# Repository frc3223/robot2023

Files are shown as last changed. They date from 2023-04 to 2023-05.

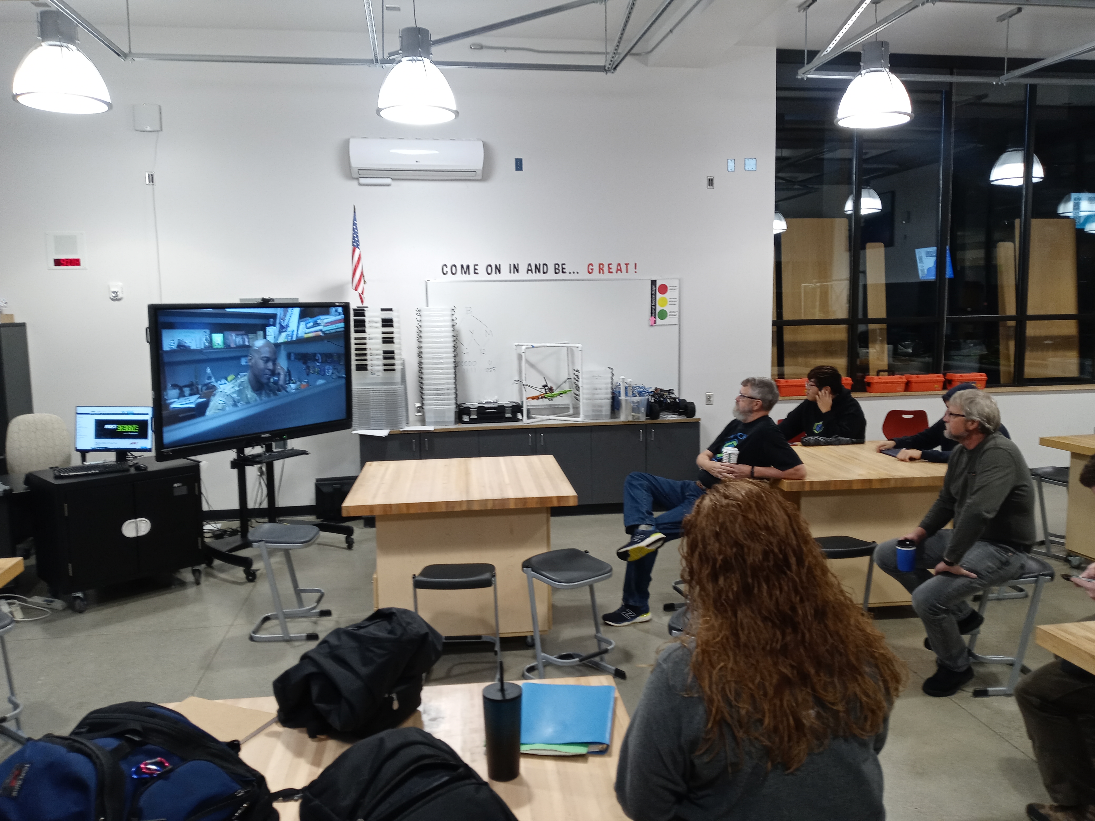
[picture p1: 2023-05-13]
Photos and Videos for RoCK/20230107_090814.jpg

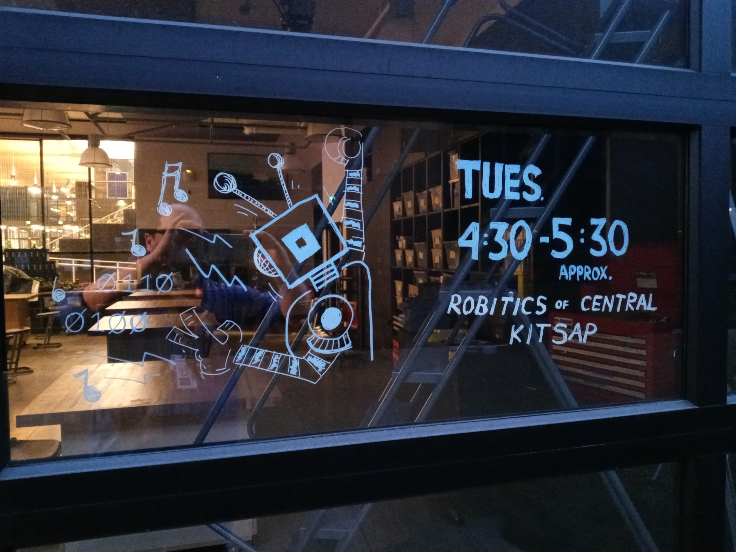
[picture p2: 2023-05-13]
Photos and Videos for RoCK/20221025_181121.jpg

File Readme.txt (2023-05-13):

We use two Audrinos.

one for the Linefollower and Winch (ROCKRadioLineFollowerEncoder)
and the other for the robotic arm. (ROCK_DOD_Challenge)

ROBOTIC ARM:
For the arm you have to use the "LAFVIN_Robot_arm_9_4_15.apk" as an app on an Android Phone. (apple is not compatible.)
you then use the "Lesson_8_Bluetooth_Controlling_Arm" code. For further opertational instruction seek LAFVIN's Lesson 8 tutorial.

Looking at the top of the robot (winch side towards you) the servos go into these spots on the audrino

left bottom servo = 5
right bottom servo = 3
servo connecting to the claw = 6**
servo that controls the claw = 9

**(Up and down controls are reversed.)

LINE FOLLOWER:
To use the Linefollower the code is "ROCKRadioLineFollowEncoder.ino"
Then, to turn on the robot's line follower, flip the left long switch all the way up on the Controller. Then flip the left small switch after alining the sensors on the robot (which is on the bottom front end of the robot) to the black line. It should follow the line.

(The Line Following Code is also a part of the Winch Code.)

WINCH:
Flip the left long switch to the middle and then flip the left small switch to activate the winch. use the left Joystick to controll the up and down motion of the winch. Left makes it go Up and Right makes it go Down.

There are indicators on the robot that changes color based on what mode you are in.

Green = Radio (the robot is in drive mode)

Orange + Winch (the robot is in Winch mode)

Red = Line Follower (the robot is in line following mode)

FINAL BUILD - CAD:
 - ARM:
	- Primary:
		- Base Piece
		- Claw Attachment
		- Claw Part
		- End Piece
		- Main Section
	- Spacers:
		- Axle Spacer
		- Base Spacer
		- Claw Mount Spacer
 - MISC.:
	- MindsEye Bracket
	- Servo Mount Bracket
There are five PRIMARY components to the arm (and their affiliated spacers). The "Base Piece" connects via four pins to the main base of the robot, which supports the rest of the arm. The "End Piece" is the first
free-rotating section of the arm (features the RoCK logo), supported by two servos. The "Main Section" features 15 hexagonal holes, allowing for a convenient way to fasten zip-ties to secure rogue wires. The "Main Section"
also attaches itself to the "End Piece", increasing the length of the arm. The "Claw Attachment" is the next free-rotating section of the arm, supported by one servo on the "Main Section". With this component, two "Claw Part" 
units move symmetrically with one servo on the "Claw Attachment".

OBSERVATIONS:
The "MindsEye Bracket" was our solution to a dilema in assembling the base of the robot. Since the manufactured steering brackets—enabling a fixed range of translational movement for the robot—were stripped due to overuse, we 
3D-printed our own.

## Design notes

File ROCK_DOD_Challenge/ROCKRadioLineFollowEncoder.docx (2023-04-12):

// ROCKRadioLineFollowEncoder 3-19-2023

#include <Servo.h>

#include <MINDSi.h>

#include "Encoder.h"

/***************************************************

/ Radio auxilliary Ch 5 & 6 are mapped to switches A & B.

/ Reads radio Ch 5 & 6 pulse widths on pins 7 & 8 and

/ chooses functions depending on radio switchs A & B positions.

/ Encoder is on digital pins 0 (A blue) and 1 (B yellow)

/ If the order is reversed, going backwards would read as positive rpm and vice versa

/ Wheel diameter is about 4.45 in.; circumference is pi*dia

/ Moving 10 feet requires (120/wheel circumference) revolutions

/ 3:1 gear ratio

/ drive motor is on pin 4 and steering is on pin 5

/ winch is on pin 6, and is controlled by radio channel 4,

/ left joystich (L/R) on arduino pin 9.

/***************************************************/

Servo steer, drive, winch;

unsigned long duration7; //pulse width on pin 7

unsigned long duration8; //pulse width on pin 8

const int inchesTravel = 120;

const float wheelDia = 4.45;

float shaftRevs = inchesTravel/(3.14 * wheelDia) * 3;

float rev;

float revStop;

const int encoderPins[2] = {0, 1}; // an array

const int threshold = 2000; // QTI threshold

bool funcB = false;

void setup() {

// Serial.begin(9600);

pinMode(11, OUTPUT); // green LED indicating radio drive

pinMode(12, OUTPUT); // red LED indicating autonomous mode

digitalWrite(11, LOW);

digitalWrite(12, LOW);

pinMode(7, INPUT); // radio channel 5

pinMode(8, INPUT); // radio channel 6

encoder::begin(encoderPins[0], encoderPins[1]);

drive.attach(4);

steer.attach(5);

drive.write(90);

steer.write(90);

winch.attach(6);

winch.write(55); // 55 sets winch "off"

// if needed, winch can be disabled by attaching it to an unused pin

delay(2000); //wait for 2 seconds to arm the ESC

}

void loop() {

duration7 = pulseIn(7, HIGH);

duration8 = pulseIn(8, HIGH);

if ((duration7 < 1250) && (duration8 < 1250)) {functionA();}

if ((duration7 > 1750) && (duration8 < 1250)) {functionB();}

if ((duration7 < 1250) && (duration8 > 1250) && (duration8 < 1750 )) {functionC();}

if ((duration7 > 1750) && (duration8 > 1250) && (duration8 < 1750 )) {functionD();}

if ((duration7 < 1250) && (duration8 > 1750)) {functionE();}

if ((duration7 > 1750) && (duration8 > 1750)) {functionF();}

// Serial.print(duration7);

// Serial.print("\t");

// Serial.println(duration8);

}

void functionA() {

// radio drive

digitalWrite(12, LOW);

digitalWrite(11, HIGH);

drive.write(getRadio(2));

steer.write(getRadio(3));

winch.write(getRadio(9));

funcB = false;

}

void functionB() {

// line follower

digitalWrite(11, LOW);

digitalWrite(12, HIGH);

rev = encoder::getRev();

revStop = rev + shaftRevs;

//run along line until rev exceeds revStop

while ((rev < revStop) && !funcB) {

drive.write(100);

// follow black line

if (QTI(A0) > threshold) {

steer.write(65);

} else if (QTI(A2) > threshold) {

steer.write(115);

} else if (QTI(A1) > threshold) {

steer.write(90);

}

rev = encoder::getRev();

duration7 = pulseIn(7, HIGH); // check if radio control changed

duration8 = pulseIn(8, HIGH);

if ((duration7 < 1250) && (duration8 < 1250)) {funcB = true;}

}

// stop motor

drive.write(90);

delay(100);

funcB = true;

}

void functionC() {Serial.println("function C");}

void functionD() {Serial.println("function D");}

void functionE() {Serial.println("function E");}

void functionF() {Serial.println("function F");}

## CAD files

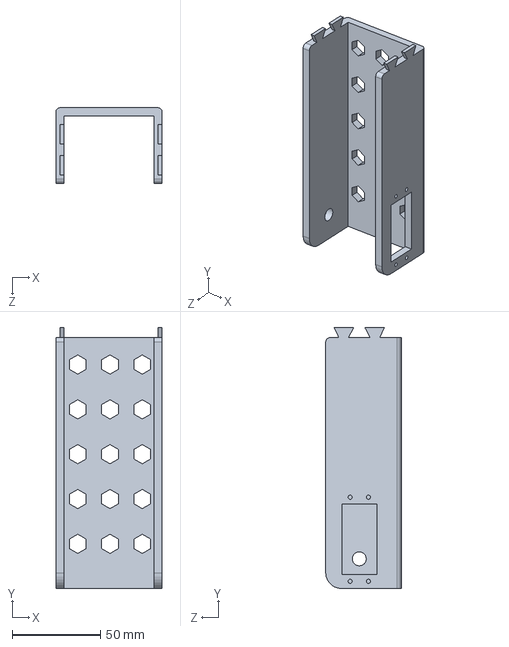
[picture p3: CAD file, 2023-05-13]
Final Build - CAD/Arm Build/Main Arm Section - Claw Attachment - Updated - Version 2.SLDPRT
60.3 x 147.9 x 42.9 mm

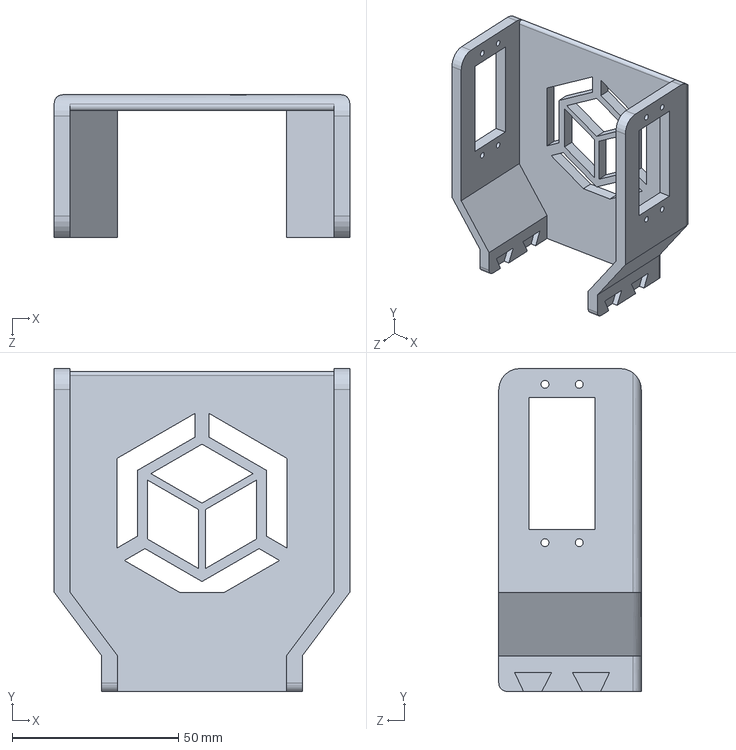
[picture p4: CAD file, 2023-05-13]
Final Build - CAD/Arm Build/Main Arm Section - End Piece - 2 Servos - Version 2.SLDPRT
88.9 x 97.2 x 42.9 mm

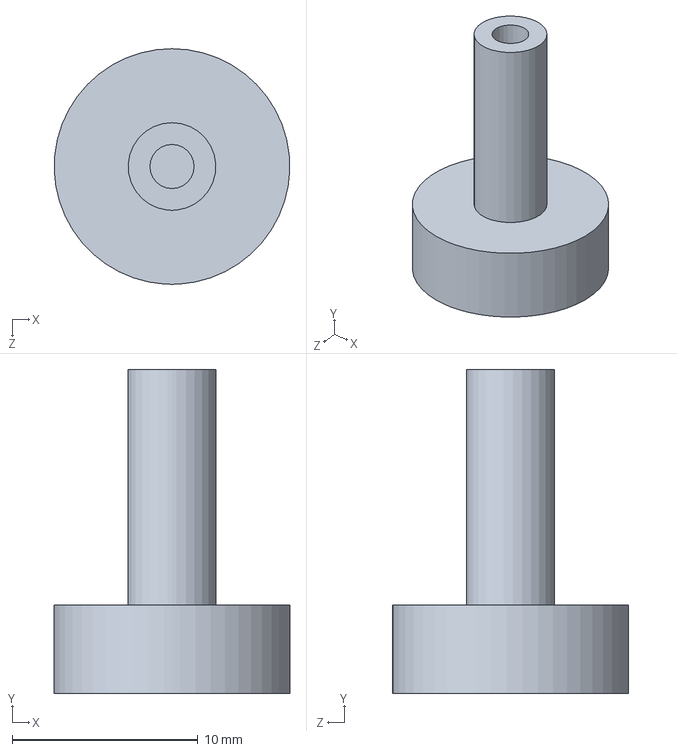
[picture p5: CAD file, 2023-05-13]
Final Build - CAD/Arm Build/Claw Mount Spacer.SLDPRT
12.7 x 17.5 x 12.7 mm

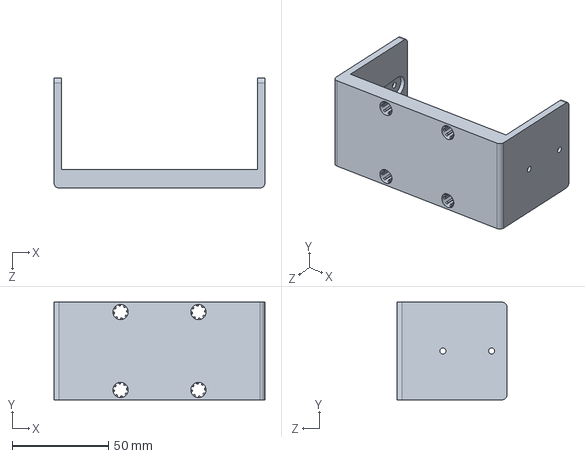
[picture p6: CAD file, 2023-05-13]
Final Build - CAD/Arm Build/Arm Base Piece - Updated - Version 4.SLDPRT
109.7 x 50.8 x 57.2 mm

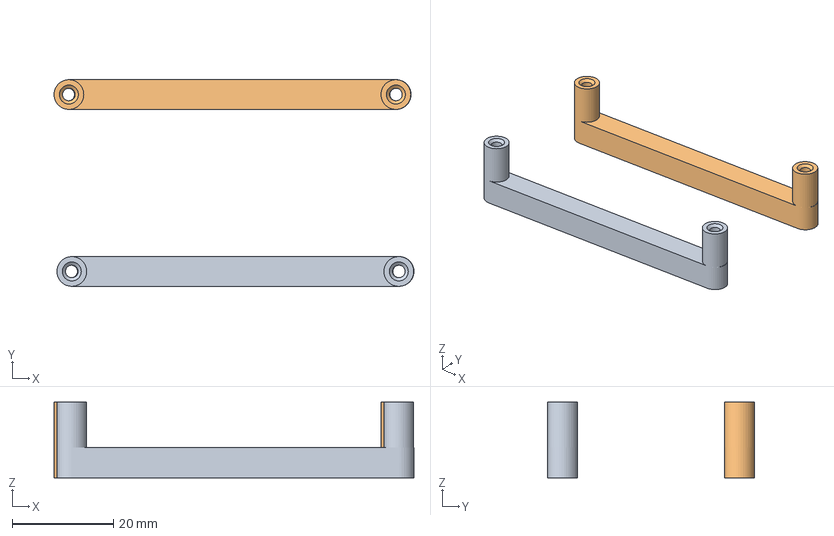
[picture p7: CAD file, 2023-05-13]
Final Build - CAD/Arm Build/AI3MSPRO_MindsEye Bracket.3mf
71.3 x 40.9 x 15.0 mm
MindsEye Bracket.STL
MindsEye Bracket.STL(1)

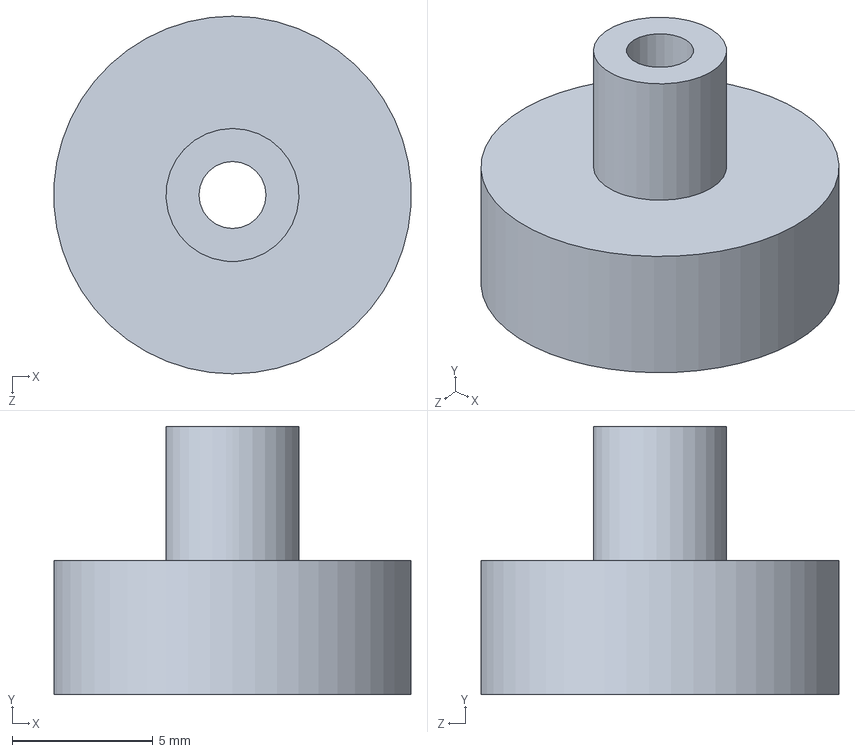
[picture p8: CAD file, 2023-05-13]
Final Build - CAD/Arm Build/Axle Spacer.SLDPRT
12.7 x 9.53 x 12.7 mm

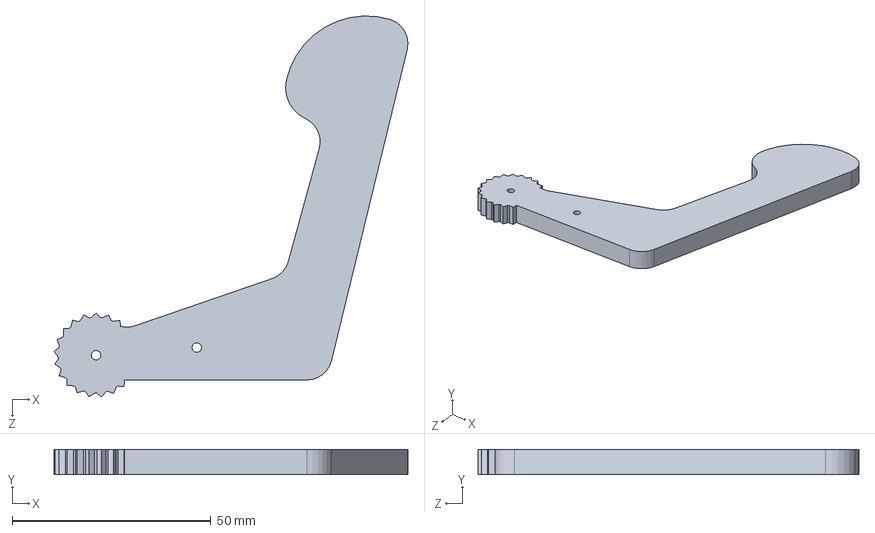
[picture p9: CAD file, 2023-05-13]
Final Build - CAD/Arm Build/Claw Part for Arm - Updated.SLDPRT
88.9 x 6.35 x 95.7 mm

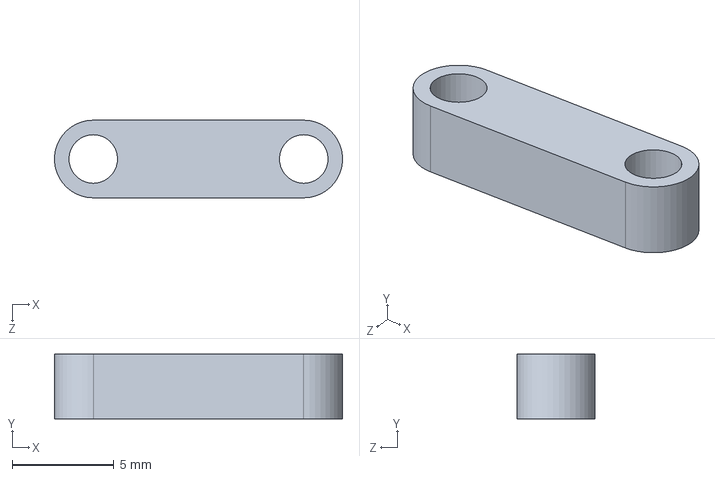
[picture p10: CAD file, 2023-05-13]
Final Build - CAD/Arm Build/Servo Mount Bracket.SLDPRT
14.1 x 3.17 x 3.81 mm

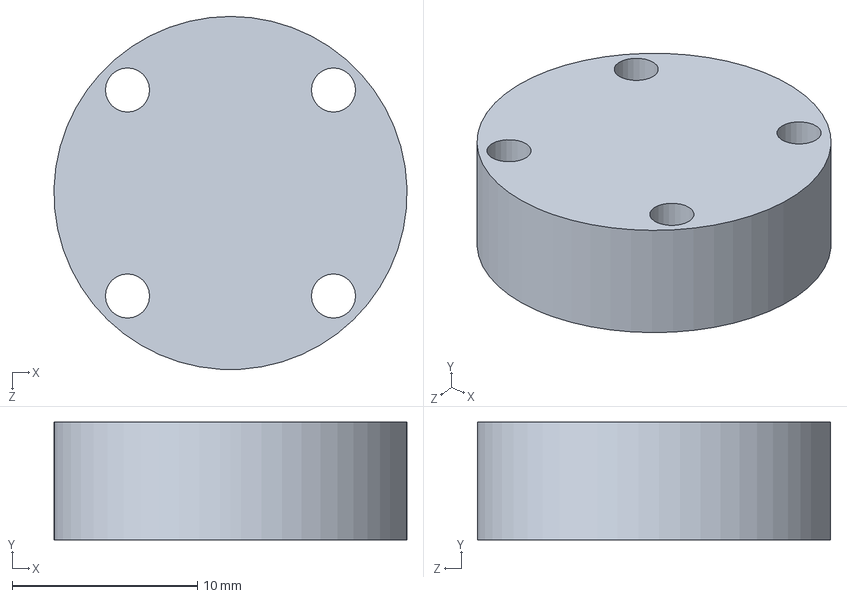
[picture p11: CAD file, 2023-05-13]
Final Build - CAD/Arm Build/Base Spacer.SLDPRT
19.0 x 6.35 x 19.1 mm

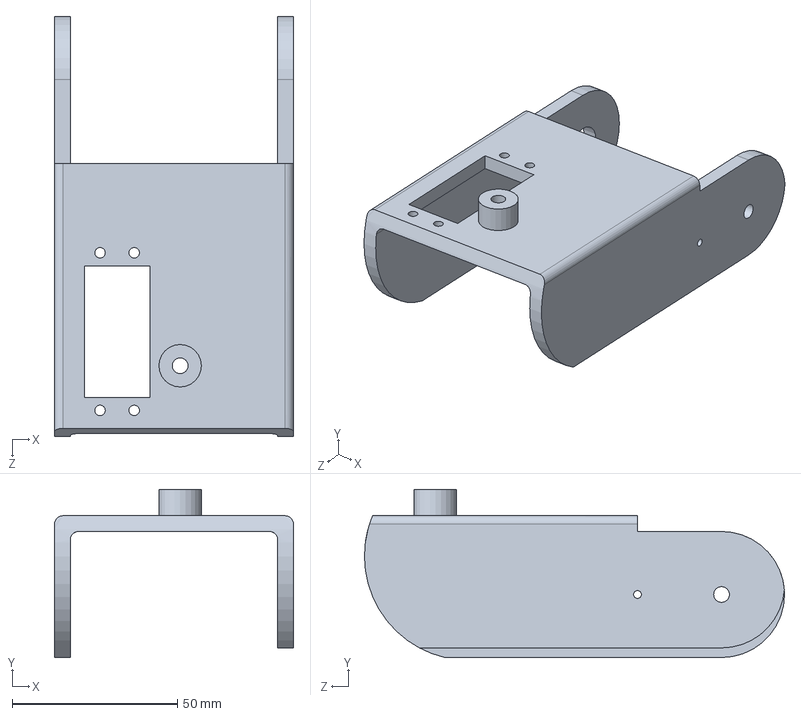
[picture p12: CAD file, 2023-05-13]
Final Build - CAD/Arm Build/Arm - Claw Attachment - Updated - Version 4.SLDPRT
72.2 x 50.8 x 127.0 mm

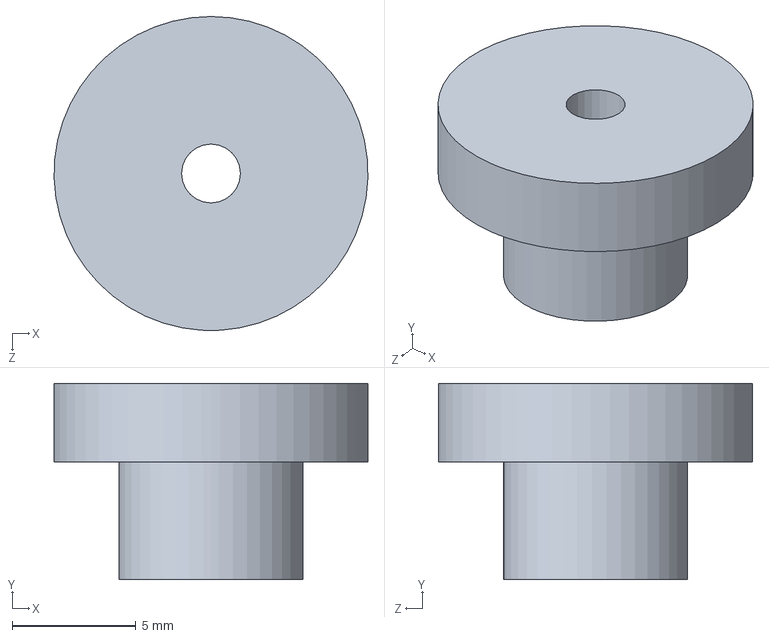
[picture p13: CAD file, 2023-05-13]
Final Build - CAD/Arm Build/Axle Spacer - Other Half.SLDPRT
12.7 x 7.94 x 12.7 mm

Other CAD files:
Final Build - CAD/Arm Build/Arm - Claw Attachment - Updated - Version 4.STL
Final Build - CAD/Arm Build/Arm Base Piece - Updated - Version 4.STL
Final Build - CAD/Arm Build/Axle Spacer - Other Half.STL
Final Build - CAD/Arm Build/Axle Spacer.STL
Final Build - CAD/Arm Build/Base Spacer.STL
Final Build - CAD/Arm Build/Claw Mount Spacer.STL
Final Build - CAD/Arm Build/Claw Part for Arm - Updated.STL
Final Build - CAD/Arm Build/Main Arm Section - Claw Attachment - Updated - Version 2.STL
Final Build - CAD/Arm Build/Main Arm Section - End Piece - 2 Servos - Version 2.STL
Final Build - CAD/Arm Build/Servo Mount Bracket.STL

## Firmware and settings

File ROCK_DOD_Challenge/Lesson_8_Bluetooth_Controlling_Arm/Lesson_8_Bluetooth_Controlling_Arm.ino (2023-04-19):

#include <Servo.h>  // add the servo libraries
//  Lesson_8_Bluetooth_Controlling_Arm mod
//  Modified so two servos control lower arm; no sideways movement
//  Slowed down servo rates by changing summation from 8 to 4
//  Moved servo limits to follow summations
Servo myservo1;  // create servo object to control a servo
Servo myservo2;
Servo myservo3;
Servo myservo4;
int pos1=90, pos2=90, pos3=90, pos4=90;  // define the variable of 4 servo angle and assign the initial value( that is the boot posture angle value)
char val;
int incomingByte = 0;          // Received data byte
String inputString = "";         // Used to store received content
boolean newLineReceived = false; // Previous data end flag
boolean startBit  = false;  //Acceptance Agreement Start Sign
int num_reveice=0;
void setup()
{
   // boot posture
  myservo1.write(pos1);  
//  delay(1000);
  myservo2.write(pos2);
  myservo3.write(pos3);
  myservo4.write(pos4);
  delay(1500);

  Serial.begin(9600); //  set the baud rate to 9600
}

void loop() 
{
  myservo1.attach(3);  // set the control pin of servo 1 to D3
  myservo2.attach(5);  // set the control pin of servo 2 to D5
  myservo3.attach(6);   // set the control pin of servo 3 to D6
  myservo4.attach(9);   // set the control pin of servo 4 to D9

while (Serial.available())
  {
    incomingByte = Serial.read();              //One byte by byte, the next sentence is read into a string array to form a completed packet
    if (incomingByte == '%')
    {
      num_reveice = 0;
      startBit = true;
    }
    if (startBit == true)
    {
      num_reveice++;
      inputString += (char) incomingByte;     
    }
    if (startBit == true && incomingByte == '#')
    {
      newLineReceived = true;
      startBit = false;
    }
    
    if(num_reveice >= 20)
    {
      num_reveice = 0;
      startBit = false;
      newLineReceived = false;
      inputString = "";
    }  
  }



if(newLineReceived)
{
 // Serial.println(inputString[1]);
    switch(inputString[1])   
    {
//      case 'B':  T_left();  break; //turn left
//      case 'C':  T_right();  break;//turn right 
      case 'A':  RB();  break;// the lower arm will draw back 
      case 'D':  RF();  break;// the lower arm will  stretch out
      case '5':  ZK();  break;//close the claw
      case '6':  ZB();  break;//close the claw
      case '4':  LB();  break;//the upper arm will lift up 
      case '7':  LF();  break;//the upper arm will go down 
      default:break;
    }

      inputString = "";   // clear the string
      newLineReceived = false;
}   
   




  
}
//**************************************************
// turn left
// This section changed so two servos control lower arm; no sideways movement
/*void T_left()
{
    pos1=pos1+8;
    if(pos1>179)
    {
      pos1=179;
    }
    myservo1.write(pos1);
    delay(5);    
}
//turn right 
void T_right()
{
    pos1=pos1-8;
    if(pos1<5)
    {
      pos1=5;
    }
    myservo1.write(pos1);
    delay(5);
}*/
//********************************************
//close the claw

void ZK()
{
      pos4=pos4-4;

      if(pos4<45)
      {
        pos4=45;
      }
  //    Serial.println(pos4);
  myservo4.write(pos4);
  delay(5);
}
// open the claw
void ZB()
{
    pos4=pos4+4;
      if(pos4>120)
      {
        pos4=120;
      }
  //      Serial.println(pos4);
  myservo4.write(pos4);
  delay(5);
}

//******************************************
// the lower arm will  stretch out;  uses two servos
void RF()
{
//    Serial.print(pos2);
//    Serial.print("\t");
    pos2=pos2-4;
//    Serial.print(pos2);
//    Serial.print("\t");
    if(pos2<5)
    {
      pos2=5;
    }
//    Serial.println(pos2);
//    Serial.print("\n");
    myservo2.write(pos2);
    pos1 = 180 - pos2;
    myservo1.write(pos1);
    delay(5);
}
// the lower arm will draw back 
void RB()
{
//    Serial.print(pos2);
//    Serial.print("\t");
    pos2=pos2+4;
//    Serial.print(pos2);
//    Serial.print("\t");
    if(pos2>175)
    {
      pos2=175;
    }
//    Serial.println(pos2);
//    Serial.print("\n");
    myservo2.write(pos2);
    pos1 = 180 - pos2;
    myservo1.write(pos1);
    delay(5);    
}

//***************************************
//the upper arm will lift up  
void LB()
{
  pos3=pos3+4;
    if(pos3>135)
    {
      pos3=135;
    }
    myservo3.write(pos3);
    delay(5);
}

//the upper arm will go down  

void LF()
{
  pos3=pos3-4;
    if(pos3<5)
    {
      pos3=5;
    }
    myservo3.write(pos3);
    delay(5);
}

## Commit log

2023-03-01 Saved off working line follower with switching options for teleoperation
2023-03-01 Added encoder project
2023-04-15 Working Bluetooth demo. Android application controls robot arm.
2023-04-19 Reorganized arduino code file structure for ease of compilation.
2023-05-10 Updated servo connectors. Included disclaimer for reversed claw controls.
2023-05-13 STL Files and Updated Readme (description of the arm).
    [AI3MSPRO_MindsEye Bracket.3mf, Arm - Claw Attachment - Updated - Version 4.SLDPRT, Arm - Claw Attachment - Updated - Version 4.STL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]
